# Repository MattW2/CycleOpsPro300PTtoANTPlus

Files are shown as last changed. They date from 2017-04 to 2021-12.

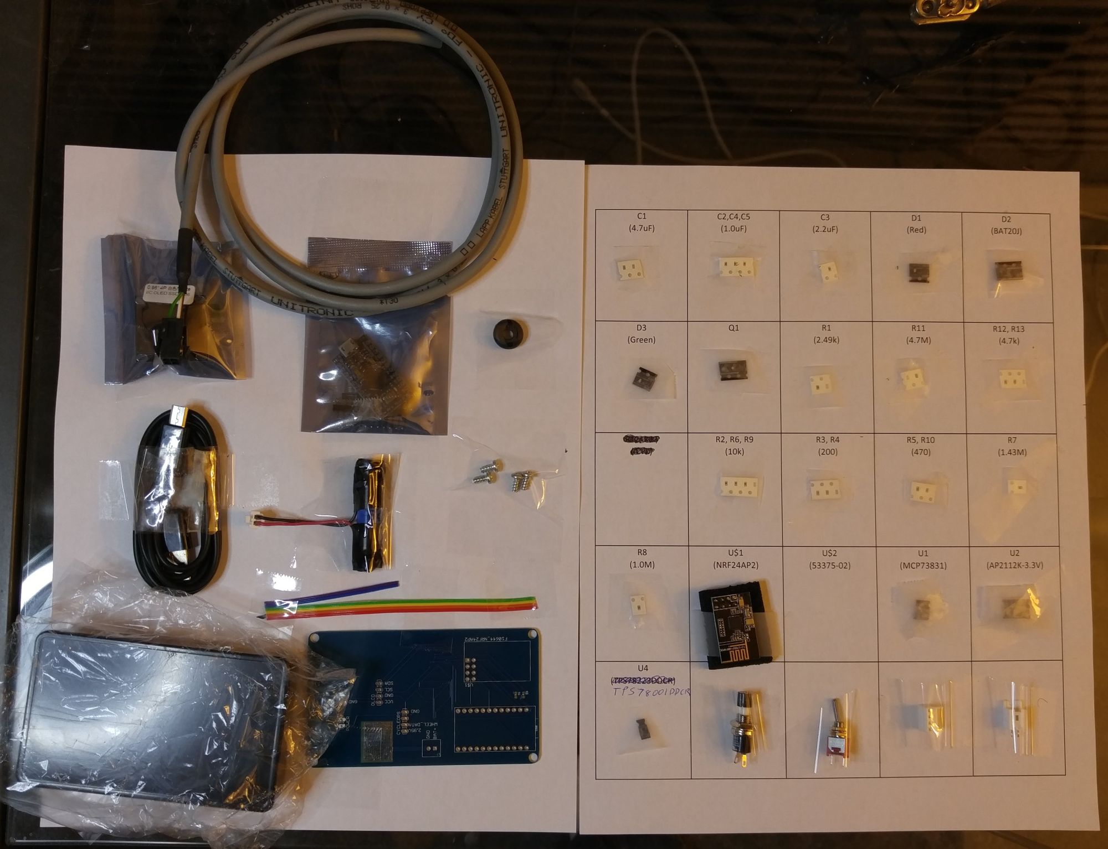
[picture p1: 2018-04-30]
PARTS KIT/Parts Kit.jpg

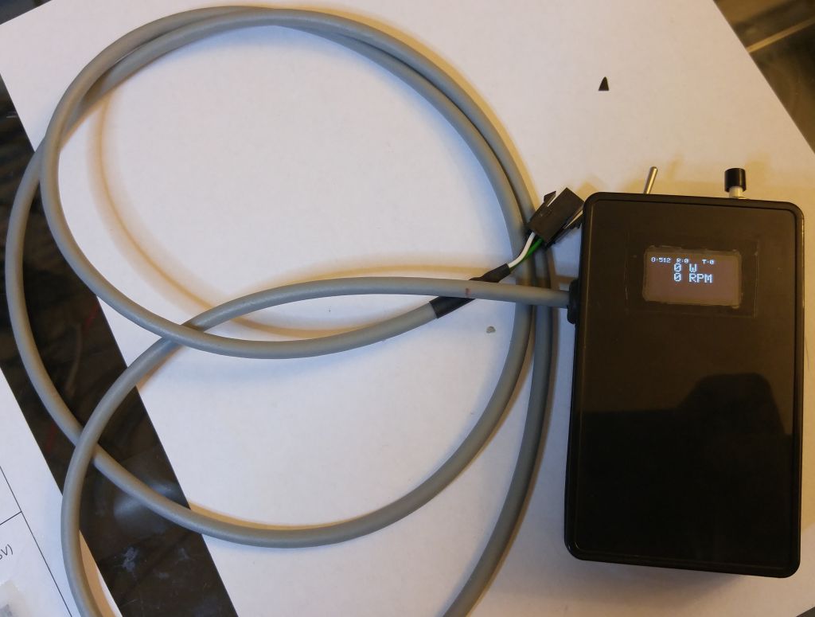
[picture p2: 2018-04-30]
PARTS KIT/Completed Unit.jpg

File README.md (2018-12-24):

# CycleOpsPro300PTtoANTPlus
Read in the raw data from the CycleOps Pro 300PT Indoor Cycle wheel and output it as a ANT+ signal using an Arduino and Nordic nRF24AP

## Background
I got a really good deal on Craigslist on this indoor bike. I had also recently become addicted to Zwift and really wanted to be able to use this with Zwift rather than use my bike on a trainer. The included computer refused to save data past about 10 minutes making it all but worthless for saving training sessions. As I find time I'll be documenting the reverse engineering and build at [https://www.blinkyme.com/](https://www.blinkyme.com/) see website for project details

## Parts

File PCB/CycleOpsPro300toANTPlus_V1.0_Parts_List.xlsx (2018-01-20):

Part | Value | Package | Description | Mouser Part # | Link | Device | Cost
B1 | PRO MICRO | SPARKFUN_PRO_MICRO | SparkFun Pro Micro |  | http://www.ebay.com/itm/Leonardo-Pro-Micro-ATmega32U4-8MHz-3-3V-Replace-ATmega328-Arduino-Pro-Mini-/131694495857 | SPARKFUN_PRO_MICRO | 8.73
Battery 14500 3.7V Li-Ion |  |  |  |  | http://www.dx.com/p/trustfire-protected-14500-3-7v-900mah-lithium-batteries-2-pack-blue-19626 |  | 2.865
C1 | 4.7uF | 0603-CAP | Capacitor | 581-06036D475MAT4A |  | CAP0603-CAP | 0.22
C2, C4, C5 | 1.0uF | 0603-CAP | Capacitor | 581-06036D105MAT2A |  | CAP0603-CAP | 0.11
C3 | 2.2uF | 0603-CAP | Capacitor | 581-06036D225MAT2A |  | CAP0603-CAP | 0.17
D1 | RED | LED-0603 | LEDs | 645-598-8010-107F |  | LED0603 | 0.45
D2 | BAT20J | SOD-323 | Schottky diodes in SFE's production catalog | 511-BAT20JFILM |  | DIODE-SCHOTTKY-BAT20J
D3 | GREEN | LED-0603 | LEDs | 645-598-8070-107F |  | LED0603 | 0.45
Molex Micro-Fit 4 Circuit plug Housing |  |  |  | 538-43020-0400 |  |  | 0.38
Molex Micro-Fit Pins |  |  |  | 538-43031-0007 |  |  | 0.92
OLED Display |  |  |  |  | http://www.ebay.com/itm/191785893008?_trksid=p2057872.m2749.l2649&ssPageName=STRK%3AMEBIDX%3AIT |  | 11.95
Power Switch |  | Mountain Switch | Toggle Switches SPST OFF-ON | 108-0041-EVX |  | 108-0041-EVX | 2.83
Project Case |  |  |  |  | http://www.ebay.com/itm/5-PCS-Plastic-Instrument-Case-Electronic-Project-Box-Enclosure-Instrument-Case-/272321315057 |  | 0.9
Q1 | 2.5A/30V | SOT23-3 | Generic PMOSFET | 621-DMG2307L-7 |  | MOSFET-PCHANNELDMG2307L
R1 | 2.49K | 0603-RES | Resistor | 660-RK73H1JTTD2491F |  | RESISTOR0603-RES
R11 | 4.7M | 0603-RES | Resistor | 660-RK73B1JTTDD475J |  | RESISTOR0603-RES
R12, R13 | 4.7K | 0603-RES | Resistor | 667-ERJ-3GEYJ472V |  | RESISTOR0603-RES
R2, R6, R9 | 10K | 0603-RES | Resistor | 660-RK73H1JTTD1002F |  | RESISTOR0603-RES
R3, R4 | 200 | 0603-RES | Resistor | 660-RK73H1JTTD2000F |  | RESISTOR0603-RES
R5, R10 | 470 | 0603-RES | Resistor | 660-RK73H1JTTD4700F |  | RESISTOR0603-RES
R7 | 1.43M | 0603-RES | Resistor | 71-CRCW06031M43FKEA |  | RESISTOR0603-RES
R8 | 1.0M | 0603-RES | Resistor | 652-CR0603FX-1004ELF |  | RESISTOR0603-RES
Reset Switch |  | Mountain Switch | Pushbutton Switches METAL BODY BLK | 103-1013-EVX |  | 103-1013-EVX | 1.85
U$1 | NRF24AP2 |  | NRF24AP2 Networking Module |  | https://www.aliexpress.com/snapshot/0.html?orderId=82384771664494 | F10644_NRF24AP2 | 15.6
U$2 | 53375-02 | 53375-02 | 2.50MM 2P VERT HDR FRCTN POS LOCK | 538-53375-0210 |  | 53375-02 | 0.43
U1 | MCP73831 | SOT23-5 | Charge management controller | 579-MCP73831T-2ACIOT |  | MCP73831 | 0.6
U2 | AP2112K-3.3V | SOT23-5 | Voltage Regulator LDO | 621-AP2112K-3.3TRG1 |  | V_REG_LDOSMD | 0.47
U4 | TPS78001DDCR | SOT95P280X110-5N | Low-Dropout Linear Regulator | 595-TPS78001DDCR |  | TPS78223DDCR | 1
 |  |  |  |  |  | Total | 49.925

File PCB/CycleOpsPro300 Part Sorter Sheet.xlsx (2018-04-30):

C1 (4.7uF) | C2,C4,C5 (1.0uF) | C3 (2.2uF) | D1 (Red) | D2 (BAT20J)
D3 (Green) | Q1 | R1 (2.49k) | R11 (4.7M) | R12, R13 (4.7k)
 | R2, R6, R9 (10k) | R3, R4 (200) | R5, R10 (470) | R7 (1.43M)
R8 (1.0M) | U$1 (NRF24AP2) | U$2 (53375-02) | U1 (MCP73831) | U2 (AP2112K-3.3V)
U4 (TPS78223DDCR)

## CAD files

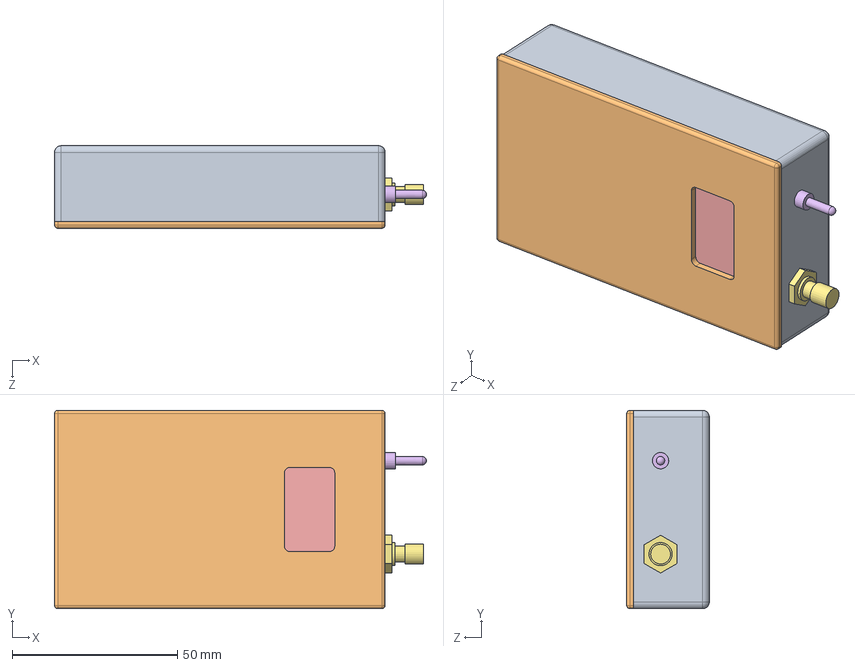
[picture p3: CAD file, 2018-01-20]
CAD/V1/CycleOpsToANTPlus.SLDASM
112.5 x 60.0 x 25.0 mm
Case XDP04-17 Bottom
Case XDP04-17 Top
cycleopspro300toantplus_v10
ARDUINO PRO MICRO
Capacitor 0603 x 5
1X04_1X04 x 2
LED_0603_R
SOD323
LED_0603_G
1X02_1X02 x 2
SOT 23
0603RES_2_5K
Resistor 0603 x 5
0603RES_5 x 5
0603RES_1_0M
0603RES_4_7M
F10644_NRF24AP2_F10644_NRF24AP2
SOT 23-5 x 2
SOT95P280X1105N_TPS78223DDCR
OLED_27x27_r2
Battery 14500

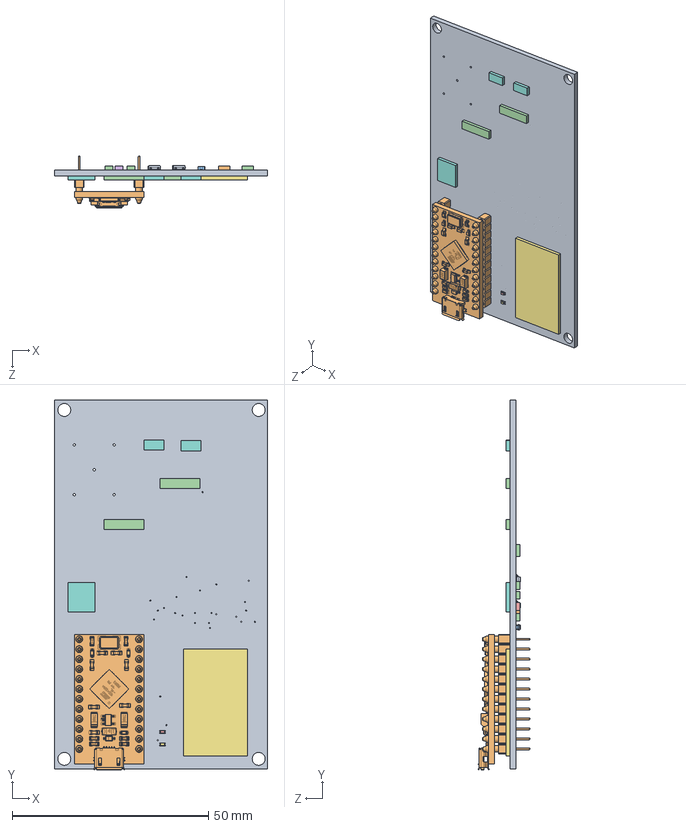
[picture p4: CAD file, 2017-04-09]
CAD/V1/cycleopspro300toantplus_v10.SLDASM
54.4 x 94.3 x 13.3 mm
cycleopspro300toantplus_v10
ARDUINO PRO MICRO
Capacitor 0603 x 5
1X04_1X04 x 2
LED_0603_R
SOD323
LED_0603_G
1X02_1X02 x 2
SOT 23
0603RES_2_5K
Resistor 0603 x 5
0603RES_5 x 5
0603RES_1_0M
0603RES_4_7M
F10644_NRF24AP2_F10644_NRF24AP2
SOT 23-5 x 2
SOT95P280X1105N_TPS78223DDCR

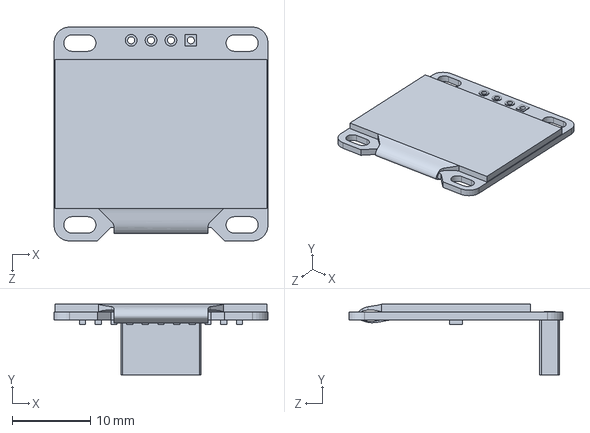
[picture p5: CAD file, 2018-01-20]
CAD/V1/OLED_27x27_r2.SLDPRT
27.3 x 9.00 x 27.3 mm

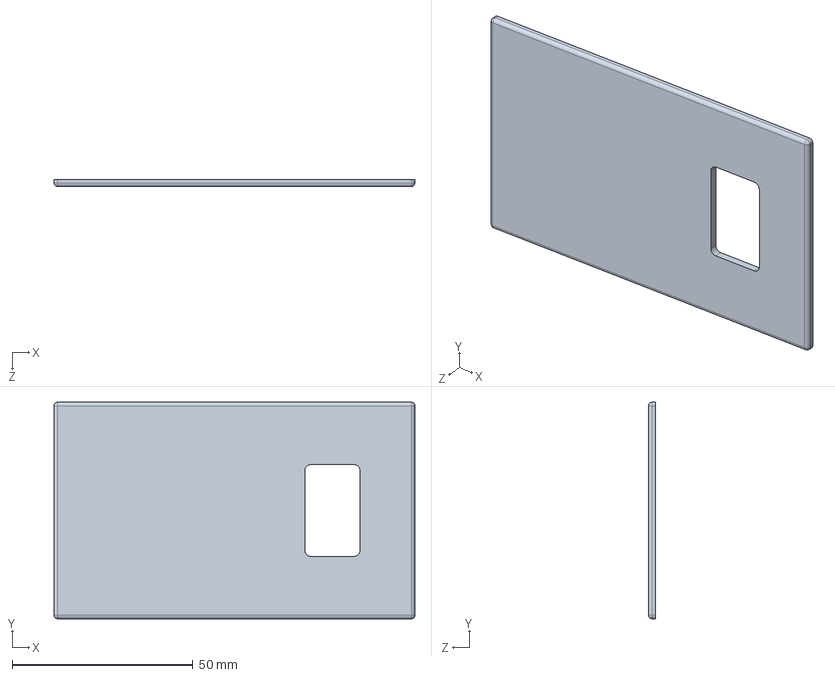
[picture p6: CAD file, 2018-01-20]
CAD/V1/Case XDP04-17 Top.SLDPRT
100.0 x 60.0 x 2.00 mm

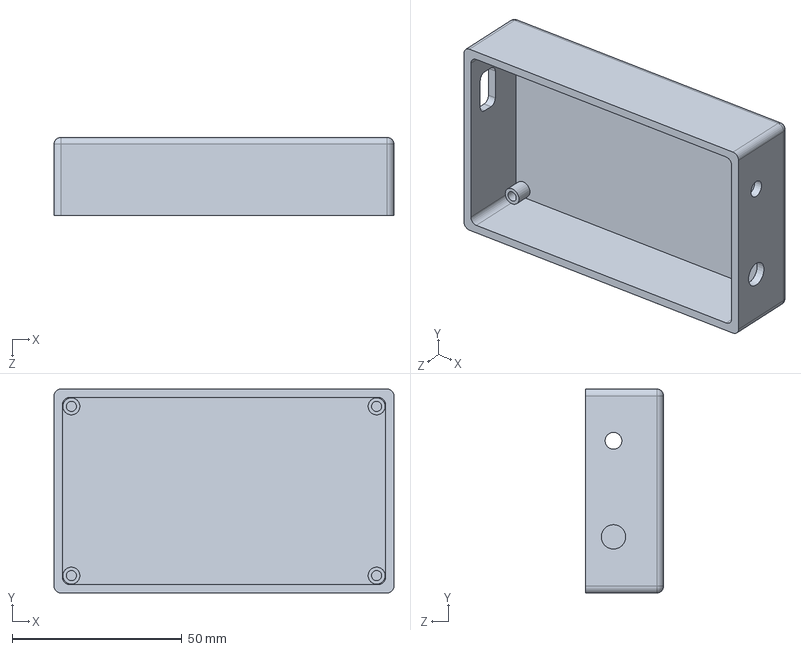
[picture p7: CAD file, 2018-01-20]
CAD/V1/Case XDP04-17 Bottom.SLDPRT
100.0 x 60.0 x 23.0 mm

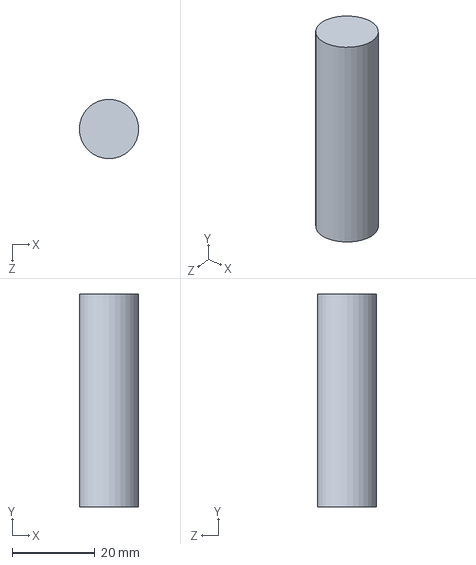
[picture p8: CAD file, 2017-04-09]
CAD/V1/Battery 14500.SLDPRT
14.4 x 51.4 x 14.4 mm

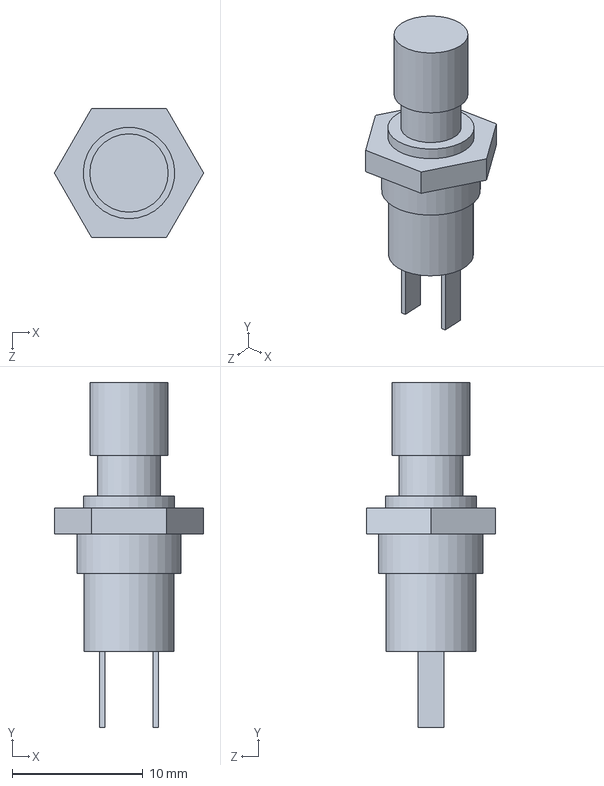
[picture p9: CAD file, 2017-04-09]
CAD/V1/Mountain Switch 103-1013-EVX.SLDPRT
11.4 x 26.4 x 9.90 mm

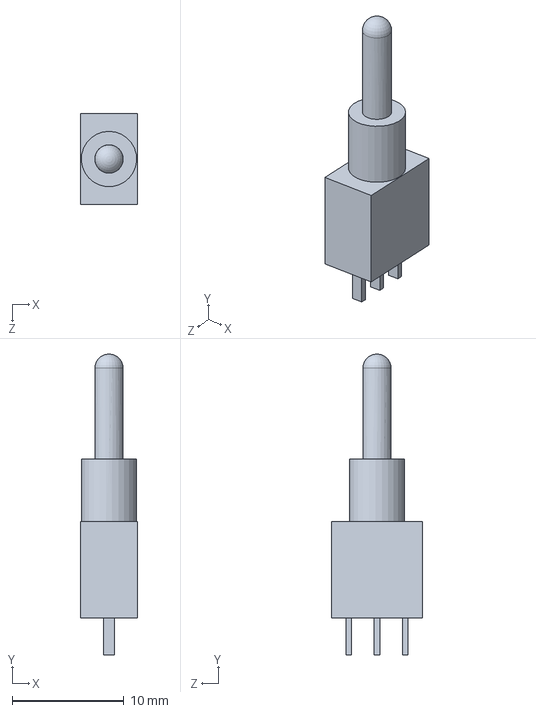
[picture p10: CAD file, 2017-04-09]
CAD/V1/Mountain Switch 108-0041-EVX.SLDPRT
5.08 x 26.9 x 8.13 mm

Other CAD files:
CAD/V1/Case XDP04-17 Bottom 8x11.SLDDRW
CAD/V1/Case XDP04-17 Bottom.SLDDRW

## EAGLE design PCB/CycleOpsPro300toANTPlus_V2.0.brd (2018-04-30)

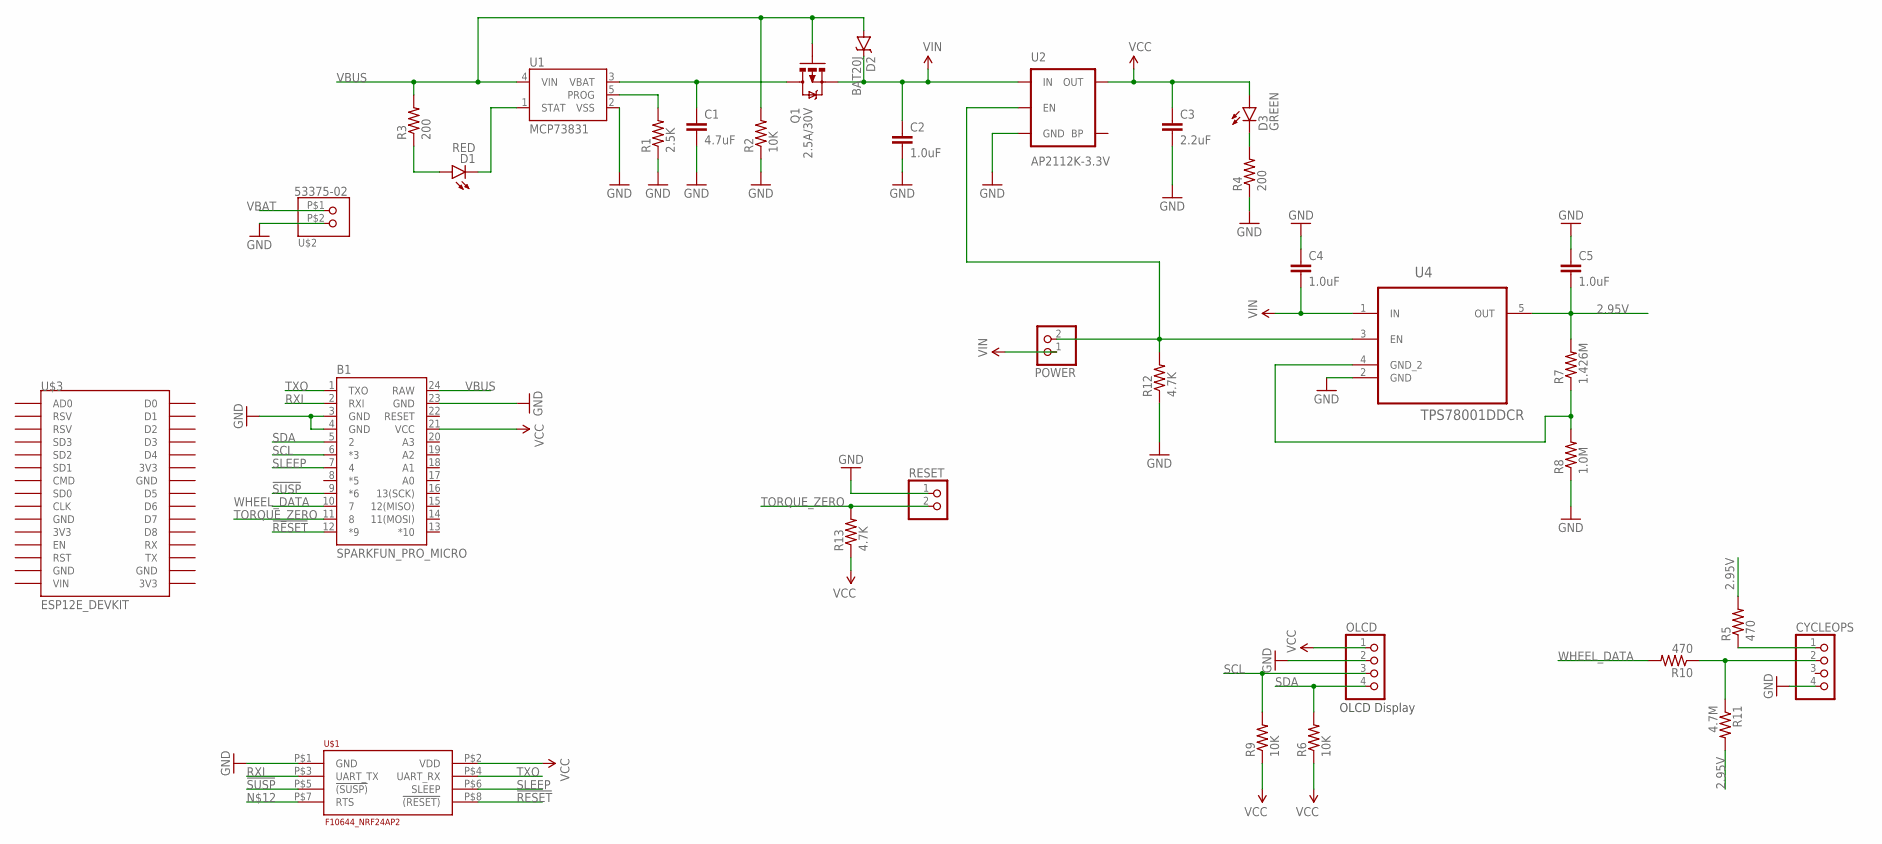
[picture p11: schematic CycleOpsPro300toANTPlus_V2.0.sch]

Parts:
B1: SPARKFUN_PRO_MICRO
C1: 4.7uF; 0603-CAP
C2, C4, C5: 1.0uF; 0603-CAP
C3: 2.2uF; 0603-CAP
CYCLEOPS: PINHD-1X4; 1X04
D1: RED; LED-0603
D2: BAT20J; SOD-323
D3: GREEN; LED-0603
OLCD: PINHD-1X4; 1X04
POWER: PINHD-1X2; 1X02
Q1: 2.5A/30V; SOT23-3
R1: 2.5K; 0603-RES
R2, R6, R9: 10K; 0603-RES
R3, R4: 200; 0603-RES
R5, R10: 470; 0603-RES
R7: 1.426M; 0603-RES
R8: 1.0M; 0603-RES
R11: 4.7M; 0603-RES
R12, R13: 4.7K; 0603-RES
RESET: PINHD-1X2; 1X02
U1: MCP73831; SOT23-5
U2: AP2112K-3.3V; SOT23-5
U4: TPS78001DDCR; SOT95P280X110-5N
U$1: F10644_NRF24AP2
U$2: 53375-02
U$3: ESP12E_DEVKIT

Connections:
2.95V: C5.2, R5.2, R7.2, R11.2, U4.5 (OUT)
!RESET: B1.12 (*9), U$1.P$8 (!(RESET))
!SUSP: B1.9 (*6), U$1.P$5 (!(SUSP))
GND: B1.3 (GND), B1.4 (GND), B1.23 (GND), C1.2, C2.2, C3.2, C4.1, C5.1, CYCLEOPS.4, OLCD.2, R1.1, R2.1, R4.1, R8.1, R12.1, RESET.1, U1.2 (VSS), U2.2 (GND), U4.2 (GND), U$1.P$1 (GND), U$2.P$2
unnamed: D1.A, R3.1
unnamed: D1.C, U1.1 (STAT)
unnamed: CYCLEOPS.1, R5.1
unnamed: R1.2, U1.5 (PROG)
unnamed: CYCLEOPS.2, R10.1, R11.1
unnamed: D3.C, R4.2
unnamed: POWER.2, R12.2, U2.3 (EN), U4.3 (EN)
unnamed: R7.1, R8.2, U4.4 (GND_2)
RXI: B1.2 (RXI), U$1.P$3 (UART_TX)
SCL: B1.6 (*3), OLCD.3, R9.2
SDA: B1.5 (2), OLCD.4, R6.2
SLEEP: B1.7 (4), U$1.P$6 (SLEEP)
TORQUE_ZERO: B1.11 (8), R13.2, RESET.2
TXO: B1.1 (TXO), U$1.P$4 (UART_RX)
VBAT: C1.1, Q1.3 (D), U1.3 (VBAT), U$2.P$1
VBUS: B1.24 (RAW), D2.A, Q1.1 (G), R2.2, R3.2, U1.4 (VIN)
VCC: B1.21 (VCC), C3.1, D3.A, OLCD.1, R6.1, R9.1, R13.1, U2.5 (OUT), U$1.P$2 (VDD)
VIN: C2.1, C4.2, D2.C, POWER.1, Q1.2 (S), U2.1 (IN), U4.1 (IN)
WHEEL_DATA: B1.10 (7), R10.2

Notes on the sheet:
OLCD Display

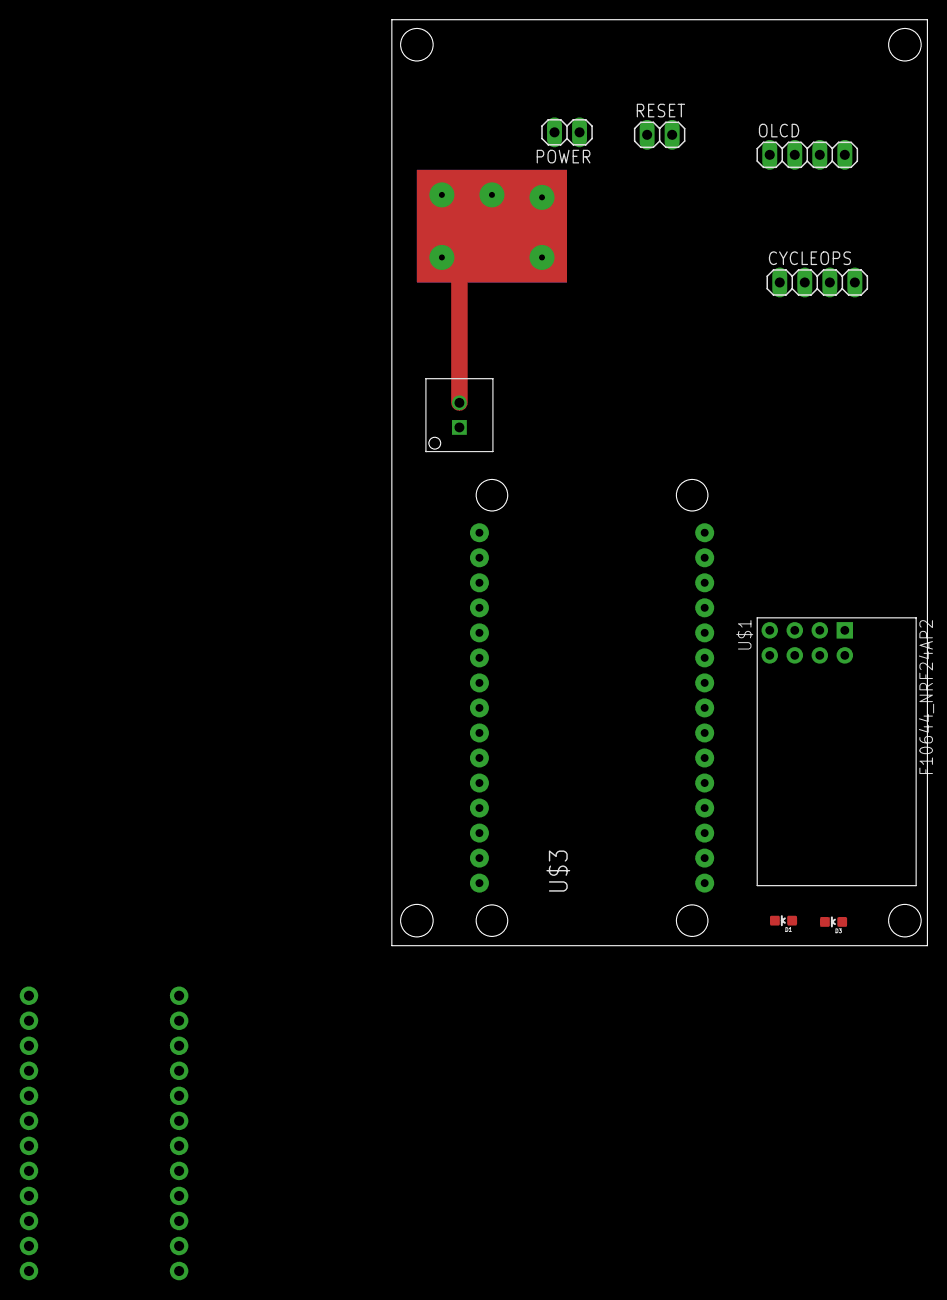
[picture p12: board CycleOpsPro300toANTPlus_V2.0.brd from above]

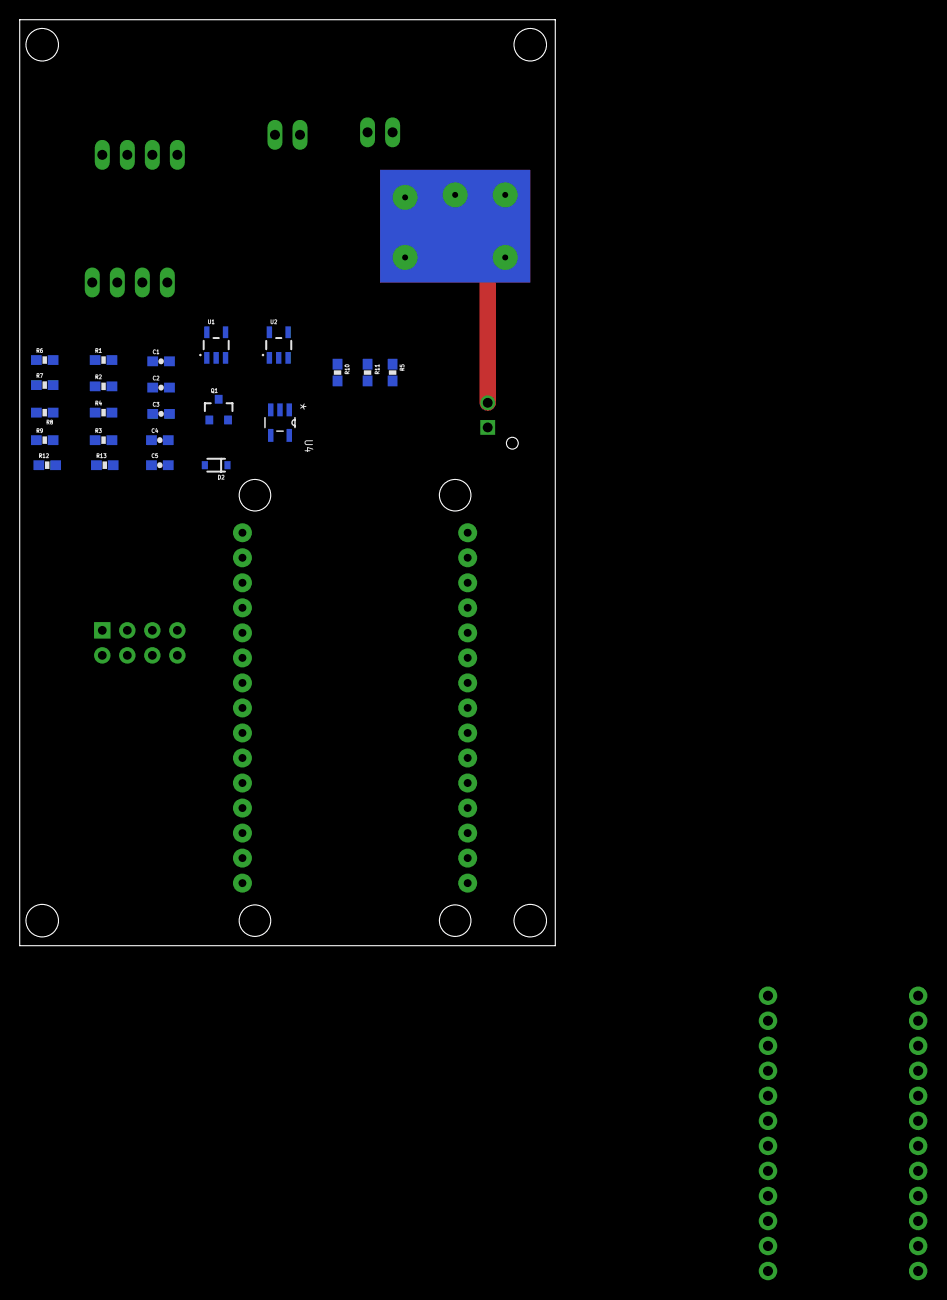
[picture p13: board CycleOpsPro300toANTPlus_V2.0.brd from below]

Board: 2 copper layers, 54.4 x 94.0 mm, 33 parts (23 on the bottom side), 23 nets.

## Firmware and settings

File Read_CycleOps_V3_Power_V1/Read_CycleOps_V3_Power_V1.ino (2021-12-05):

#define UCHAR unsigned char
#define MESG_TX_SYNC ((UCHAR)0xA4)
#define MESG_SYSTEM_RESET_ID ((UCHAR)0x4A)
#define MESG_NETWORK_KEY_ID ((UCHAR)0x46)
#define MESG_ASSIGN_CHANNEL_ID ((UCHAR)0x42)
#define MESG_CHANNEL_ID_ID ((UCHAR)0x51)
#define MESG_CHANNEL_RADIO_FREQ_ID ((UCHAR)0x45)
#define MESG_CHANNEL_MESG_PERIOD_ID ((UCHAR)0x43) // Set channel period 0x43
#define MESG_RADIO_TX_POWER_ID ((UCHAR)0x47) // Set Tx Power 0x47
#define MESG_CHANNEL_SEARCH_TIMEOUT_ID ((UCHAR)0x44) // Set Channel Search Timeout 0x44
#define MESG_OPEN_CHANNEL_ID ((UCHAR)0x4B) // ID Byte 0x4B
#define MESG_BROADCAST_DATA_ID ((UCHAR)0x4E)

//OLED Display
#define USE_OLCD
#include "SSD1306Ascii.h"
#include "SSD1306AsciiAvrI2c.h"

#include <Bounce2.h>

//Pins for ANT+ Device Display
#define RTS_PIN 2
#define SUSPEND 6
#define SLEEP 4
#define RESET 9

//Pins for Torque Zero Button
#define TORQUE_ZERO_PIN 8

//Pins for Data and Debug
#define WHEEL_DATA 7
#define CLOCK_OUT 16
#define ERROR_OUT 10

//Conversion Constants
#define WHEEL_SPEED_CONVERSION 6283185.30718
#define TORQUE_INLBS_TO_NM 0.112984829
// #define WHEEL_CIRCUMFERENCE_MM 1827 //this is not used in code, but needed to set your bike computer to read the correct speed
#define BIKE_WHEEL_ROTATIONS_PER_SEC_PER_RPM 0.06303072228348
#define MPH_PER_RPM 0.257173772

#if defined(USE_OLCD)
//OLED Display
#define OLED_RESET -1
// 0X3C+SA0 - 0x3C or 0x3D
#define I2C_ADDRESS 0x3C
SSD1306AsciiAvrI2c display; 
#endif

#define MAX_DATA_PAGE_INDEX 5


// ****************************************************************************
// *************************  GLOBALS for Read CycelOps************************
// ****************************************************************************
static const double WHEEL_SLOPE = 527.2213800;
static const double WHEEL_OFFSET = -3181.8199961;
static const double GEAR_RATIO = 0.269230769;
static const bool VALID_START_DATA[15] = {0,1,1,1,1,0,1,0,1,1,0,1,1,0,1};

int TORQUE_OFFSET = 512;

boolean start_reading;
boolean reset_ready;
volatile boolean new_data_set;
volatile boolean is_data_bit;
volatile int bit_read_count;
int bit_delay;

int data_bits = 50;

//Timers
unsigned long current_time_us;
volatile unsigned long last_time_us;
unsigned long delay_reset_us;
unsigned long wheel_time_now_ms;
unsigned long wheel_time_last_ms;

//Timers and switch for finding error bits
volatile unsigned long last_rising_edge;
volatile unsigned long last_falling_edge;
volatile boolean error_bit_found;
boolean data_being_read;

//array to store data
boolean data_input[70];
int data_position;
int torque;
int torque_in_lbs;
unsigned int wheel_speed;
unsigned int CycleOps_CheckSum;
double wheel_period; //time in us for 1 wheel rotation

// Instantiate a Bounce object for zeroing the torque
Bounce torque_zero_input = Bounce();


// ****************************************************************************
// *************************  GLOBALS for Power Out**********************
// ****************************************************************************

const int Mag_pickup = 3; // the number of the pushbutton pin
//int pin = 13;
volatile int state = LOW;
//unsigned long time1;
//unsigned long time2;
//unsigned long period;

double omega;
double torque_kgm;
double torque_Nm;

byte ANT_event = 0;
uint16_t ANT_INST_power = 0;
uint16_t ANT_power = 0;
uint8_t ANT_icad = 0; // Corrected Cadence
double powerconst;

// ****************************************************************************
// *************************  GLOBALS for Cadance Out**************************
// ****************************************************************************
uint8_t ANT_wheel_ticks = 0;
uint16_t ANT_wheel_period = 0;
uint16_t ANT_accumulated_torque = 0;
double Bike_Speed_MPH = 0;

boolean recalc = 0;

long lastDebounceTime = 0; // the last time the output pin was toggled
long debounceDelay = 30; // the debounce time; increase if the output flickers
int buttonState; // the current reading from the input pin
int lastButtonState = LOW; // the previous reading from the input pin
boolean sent = 0;
int data_page_index = 0;

void setup()
{
	//setup for CycelOp
	data_position = 0;
	start_reading = 0;
	new_data_set = 0;
	reset_ready = 0;
	//wheel_time_now = 0;
	//wheel_time_last = 0;
	bit_read_count = 0;

	torque = 0;
	torque_in_lbs = 0;
	ANT_icad = 0;
	ANT_INST_power = 0;
	CycleOps_CheckSum = 0;

  ANT_wheel_ticks = 0;
  ANT_wheel_period = 0;
  ANT_accumulated_torque = 0;
	
	last_rising_edge = 0;
	last_falling_edge = 0;
	error_bit_found = 0;
	data_being_read = 0;

  data_page_index = 0;

	digitalWrite(CLOCK_OUT, LOW);
	digitalWrite(ERROR_OUT, LOW);

	pinMode(WHEEL_DATA, INPUT);
	pinMode(CLOCK_OUT, OUTPUT);
	pinMode(ERROR_OUT, OUTPUT);

	//setup for Torque zero button
	pinMode(TORQUE_ZERO_PIN, INPUT_PULLUP);
	// After setting up the button, setup the Bounce instance :
	torque_zero_input.attach(TORQUE_ZERO_PIN);
	torque_zero_input.interval(50); // interval in ms

	//Setup for PowerOut
	pinMode(SUSPEND, OUTPUT);           // set pin to output
	pinMode(SLEEP, OUTPUT);             // set pin to output
	pinMode(RESET, OUTPUT);             // set pin to output
	pinMode(RTS_PIN, INPUT);            // set pin to input

	digitalWrite(RESET, HIGH);        // turn on pullup resistors
	digitalWrite(SUSPEND, HIGH);      // turn on pullup resistors
	digitalWrite(SLEEP, LOW);         // turn on pullup resistors

	Serial.begin(115200); //this is the USB port serial
	Serial1.begin(9600); //this is the hardware UART

	delay(1000);
	Serial1.flush();

	//reset the ANT+ module
	digitalWrite(RESET, LOW);       // turn on pullup resistors
	delay(5);
	digitalWrite(RESET, HIGH);       // turn on pullup resistors

#if defined(USE_OLCD)
	//Setup for OLCD
	// by default, we'll generate the high voltage from the 3.3v line internally! (neat!)
#if OLED_RESET >= 0
	display.begin(&Adafruit128x64, I2C_ADDRESS, RST_PIN);
#else // OLED_RESET >= 0
	display.begin(&Adafruit128x64, I2C_ADDRESS);
#endif // OLED_RESET >= 0
	// Call display.setI2cClock(frequency) to change from the default frequency.
	display.setFont(Adafruit5x7);    
	display.clear(); 

	// setup display with no data
	display.set1X();
	display.setCursor(0, 0); // begin text at this location, X,Y
	display.print(F("O:"));
	display.setCursor(40, 0); // begin text at this location, X,Y
	display.print(F("R:"));
	display.setCursor(80, 0); // begin text at this location, X,Y
	display.print(F("T:"));
	display.setCursor(0, 1); // begin text at this location, X,Y
	display.set2X();  
	display.print(F("  W:"));  
	display.setCursor(0, 4); // begin text at this location, X,Y  
	display.print(F("RPM:"));
#endif

	delay(50);
	initiate();
	delay(20);

	ant_send_basicpower();

	//interrupt for wheel data from CycleOps
	attachInterrupt(digitalPinToInterrupt(WHEEL_DATA), find_start_of_wheel_data, CHANGE);

	current_time_us = micros();
	last_time_us = current_time_us;
  
  wheel_time_now_ms = millis();
  wheel_time_last_ms = wheel_time_now_ms;
}

void loop()
{
	int i;
  unsigned long wheel_time_delta_ms;
  
	current_time_us = micros();

	if (new_data_set) {
		start_reading = 1;
		//Serial.print("found start = ");
		//Serial.println(current_time_us);
		new_data_set = 0;
	}

	if (is_data_bit)
		//bit_delay = 1765;
		bit_delay = 1875; //delay for data bits
	else
		//bit_delay = 1525;
		bit_delay = 8780; //delay for dead bits

	if (is_data_bit && bit_read_count == 4) {
		is_data_bit = 0;
		bit_read_count = 0;
	}

	if (!is_data_bit && bit_read_count == 1) {
		is_data_bit = 1;
		bit_read_count = 0;
	}

	if ((current_time_us - last_time_us) >= bit_delay) {
		if (start_reading && data_position < data_bits) {
			last_time_us = current_time_us;
			read_wheel_data();
			bit_read_count++;
		}
	}
	
	if (data_position == data_bits) { //time to spit out the data and reset
		start_reading = 0;
		//test if data is valid
		if (memcmp(data_input,VALID_START_DATA,15) == 0 && !error_bit_found) {			
			read_torque();
			read_speed();
			//read_checkSum();
			recalc = 1;
			data_position = 0;
			delay_reset_us = current_time_us;
			reset_ready = 1;
			error_bit_found = 0;
			digitalWrite(ERROR_OUT, LOW);
		} else { //data is not valid, clear buffer
			if (error_bit_found) {
				Serial.println(F("ERROR BIT FOUND"));
			}
			data_position = 0;
			delay_reset_us = current_time_us;
			reset_ready = 1;
			error_bit_found = 0;
			digitalWrite(ERROR_OUT, LOW);
		}
	}
	
	if (reset_ready && ((current_time_us - delay_reset_us) > 100000)) {
		reset_ready = 0;
		bit_read_count = 0;
		error_bit_found = 0;
	}

	if (recalc == 1)
	{
		ANT_icad = uint8_t(omega * 9.549296586 * GEAR_RATIO); // Cadence (RPM)

		ANT_INST_power = uint16_t(torque_Nm * omega); // Instant power calculation
		ANT_power += ANT_INST_power; // Incremental power calculation

    //values for wheel speed Data Page (0x11)
    wheel_time_now_ms = millis();
    wheel_time_delta_ms = wheel_time_now_ms - wheel_time_last_ms;
    wheel_time_last_ms = wheel_time_now_ms;
    
    ANT_wheel_ticks += uint8_t((wheel_time_delta_ms * ANT_icad * BIKE_WHEEL_ROTATIONS_PER_SEC_PER_RPM) / 1000);
    if (ANT_icad > 0)
    {
      ANT_wheel_period += uint16_t(1/(ANT_icad * BIKE_WHEEL_ROTATIONS_PER_SEC_PER_RPM ) * 2048);
    }
    ANT_accumulated_torque += uint16_t(torque_Nm * 32); // Accumulated torque calculation
    Bike_Speed_MPH = ANT_icad * MPH_PER_RPM;
    
	//write data to serial out
		for (i = 0; i <= data_bits; i++) {
			Serial.print(data_input[i]);
		}
		Serial.print(F(" "));
		Serial.print(torque, DEC);
		Serial.print(F(" "));
		Serial.print(wheel_speed, DEC);
		Serial.print(F(" "));
		Serial.print(ANT_icad, 1);
		Serial.print(F(" "));
		Serial.print(ANT_INST_power, 1);
		Serial.print(F(" "));
		//Serial.print(CycleOps_CheckSum, DEC);
    Serial.print(ANT_wheel_ticks, 1);
    Serial.print(F(" "));
    Serial.print(ANT_wheel_period, 1);
    Serial.print(F(" "));
    Serial.print(ANT_accumulated_torque, 1);
		Serial.println(F(""));

    if (data_page_index == 0)
    {
      ANT_event++;
      ant_send_basicpower(); // Main ANT tranmission of Basic Power Data and RPM
    }
    if (data_page_index >= 1)
    {
      ANT_event++;
      ant_send_wheel_torque(); //Main Ant transmission of wheel speed (for bike speed)
    }
    data_page_index++;
    if (data_page_index >= MAX_DATA_PAGE_INDEX)
    {
      data_page_index = 0;
    }
		Serial1.flush();

#if defined(USE_OLCD)
		update_OLED();
#endif
		recalc = 0;
	}

	// Update the Bounce instance :
	torque_zero_input.update();
	if (!torque_zero_input.read())
	{
		TORQUE_OFFSET = torque;
		update_OLED();
	}

}

UCHAR checkSum(UCHAR *data, int length)
{
	int i;
	UCHAR chksum = data[0];
	for (i = 1; i < length; i++)
	chksum ^= data[i]; // +1 since skip prefix sync code, we already counted it
	return chksum;
}

void reset ()
{
	uint8_t buf[5];
	buf[0] = MESG_TX_SYNC; // SYNC Byte 0xA4
	buf[1] = 0x01; // LENGTH Byte
	buf[2] = MESG_SYSTEM_RESET_ID; // 0x4A
	buf[3] = 0x00; // Data Byte N (N=LENGTH)
	buf[4] = checkSum(buf, 4);
	ANTsend(buf, 5);
}

void SetNetwork() //thisisANT.com and become an ANT+ Adopter
{
	uint8_t buf[13];
	buf[0] = MESG_TX_SYNC; // SYNC Byte 0xA4
	buf[1] = 0x09; // LENGTH Byte
	buf[2] = MESG_NETWORK_KEY_ID; // ID Byte 0x46
	buf[3] = 0x00; // Data Byte N (Network Number)
	buf[4] = 0xB9; // Data Byte N (Public Network Key)
	buf[5] = 0xA5; // Data Byte N (Public Network Key)
	buf[6] = 0x21; // Data Byte N (Public Network Key)
	buf[7] = 0xFB; // Data Byte N (Public Network Key)
	buf[8] = 0xBD; // Data Byte N (Public Network Key)
	buf[9] = 0x72; // Data Byte N (Public Network Key)
	buf[10] = 0xC3; // Data Byte N (Public Network Key)
	buf[11] = 0x45; // Data Byte N (Public Network Key)
	buf[12] = checkSum(buf, 12);
	ANTsend(buf, 13);
}
void assignch()
{
	uint8_t buf[7];
	buf[0] = MESG_TX_SYNC; // SYNC Byte 0xA4
	buf[1] = 0x03; // LENGTH Byte
	buf[2] = MESG_ASSIGN_CHANNEL_ID; // 0x42
	buf[3] = 0x00; // Channel Number
	buf[4] = 0x10; // Channel Type
	buf[5] = 0x00; // Network Number
	buf[6] = checkSum(buf, 6);
	ANTsend(buf, 7);
}

void SetChID()
{
	uint8_t buf[9];
	buf[0] = MESG_TX_SYNC; // SYNC Byte 0xA4
	buf[1] = 0x05; // LENGTH Byte
	buf[2] = MESG_CHANNEL_ID_ID; // Assign Channel ID 0x51
	buf[3] = 0x00; // channel number
	buf[4] = 0x06; // Device number
	buf[5] = 0x00; // Device number
	buf[6] = 0x0B; //Device type ID
	buf[7] = 0x00; //Transmission type -CHANGED
	buf[8] = checkSum(buf, 8);
	ANTsend(buf, 9);
}

void ANTsend(uint8_t buf[], int length) {
	//Serial.print("ANTsend TX: ");
	for (int i = 0 ; i <= length ; i++)
	{
		//Serial.print(buf[i], HEX);
		//Serial.print(" ");
		Serial1.write(buf[i]);
	}
	//Serial.println("");
}
void SetFreq()
{
	uint8_t buf[6];
	buf[0] = MESG_TX_SYNC; // SYNC Byte 0xA4
	buf[1] = 0x02; // LENGTH Byte
	buf[2] = MESG_CHANNEL_RADIO_FREQ_ID; // Set Channel RF Freq 0x45
	buf[3] = 0x00; // Channel number
	buf[4] = 0x39; // Frequency
	buf[5] = checkSum(buf, 5);
	ANTsend(buf, 6);
}

void SetPeriod()
{
	uint8_t buf[7];
	buf[0] = MESG_TX_SYNC; // SYNC Byte 0xA4
	buf[1] = 0x03; // LENGTH Byte
	buf[2] = MESG_CHANNEL_MESG_PERIOD_ID; // Set channel period 0x43
	buf[3] = 0x00; // Channel number
	buf[4] = 0xF6; // Messaging Period byte1
	buf[5] = 0x1f; // Messaging period byte2
	buf[6] = checkSum(buf, 6);
	ANTsend(buf, 7);
}

void SetPower()
{
	uint8_t buf[6];
	buf[0] = MESG_TX_SYNC; // SYNC Byte 0xA4
	buf[1] = 0x02; // LENGTH Byte
	buf[2] = MESG_RADIO_TX_POWER_ID; // Set Tx Power 0x47
	buf[3] = 0x00; // Channel Number
	buf[4] = 0x03; // Tx power
	buf[5] = checkSum(buf, 5);
	ANTsend(buf, 6);
}

void SetTimeout()
{
	uint8_t buf[6];
	buf[0] = MESG_TX_SYNC; // SYNC Byte 0xA4
	buf[1] = 0x02; // LENGTH Byte
	buf[2] = MESG_CHANNEL_SEARCH_TIMEOUT_ID; // Set Channel Search Timeout 0x44
	buf[3] = 0x00; // Channel number
	buf[4] = 0x1E; // Set timeout
	buf[5] = checkSum(buf, 5);
	ANTsend(buf, 6);
}

void OpenChannel()
{
	uint8_t buf[5];
	buf[0] = MESG_TX_SYNC; // SYNC Byte 0xA4
	buf[1] = 0x01; // LENGTH Byte
	buf[2] = MESG_OPEN_CHANNEL_ID; // ID Byte 0x4B
	buf[3] = 0x00;
	buf[4] = checkSum(buf, 4);
	ANTsend(buf, 5);
}

void initiate()
{
	SetNetwork();
	delay(100);
	assignch();
	delay(100);
	SetChID();
	delay(100);
	SetFreq();
	delay(100);
	SetPeriod();
	delay(100);
	SetPower();
	delay(100);
	SetTimeout();
	delay(100);
	OpenChannel();
	delay(100);
}

void ant_send_basicpower()
{
	uint8_t buf[13];
	buf[0] = MESG_TX_SYNC; // SYNC Byte 0xA4
	buf[1] = 0x09; // LENGTH Byte
	buf[2] = MESG_BROADCAST_DATA_ID; // 0x4E
	buf[3] = 0x00; // Channel number
	buf[4] = 0x10; // Standard Power-Only Message, Byte 0
	buf[5] = ANT_event; // Power Event Count, Byte 1
	buf[6] = 0xFF; // Pedal Power, Byte 2, 0xFF, Pedal Power Not Used
	buf[7] = ANT_icad; // Instant Cadence, RPM, Byte 3
	buf[8] = byte(ANT_power & 0xFF); // Accumulated power LSB, Byte 4
	buf[9] = byte((ANT_power >> 8) & 0xFF); // Accumulated power MSB, Byte 5
	buf[10] = byte(ANT_INST_power & 0xFF); // Instant power LSB, Byte 6
	buf[11] = byte((ANT_INST_power >> 8) & 0xFF); // Instant power MSB, Byte 7
	buf[12] = checkSum(buf, 12);
	ANTsend(buf, 13);
}

void ant_send_wheel_torque()
{
  uint8_t buf[13];
  buf[0] = MESG_TX_SYNC; // SYNC Byte 0xA4
  buf[1] = 0x09; // LENGTH Byte
  buf[2] = MESG_BROADCAST_DATA_ID; // 0x4E
  buf[3] = 0x00; // Channel number
  buf[4] = 0x11; // 0x11 – sensor measures torque at wheel, Byte 0
  buf[5] = ANT_event; // Event counter increments with each information update, Byte 1
  buf[6] = byte(ANT_wheel_ticks); // Wheel tick count increments with each wheel revolution, Byte 2
  buf[7] = ANT_icad; // Instant Cadence, RPM, Byte 3
  buf[8] = byte(ANT_wheel_period & 0xFF); // Accumulated wheel period LSB, Byte 4
  buf[9] = byte((ANT_wheel_period >> 8) & 0xFF); // Accumulated wheel period  MSB, Byte 5
  buf[10] = byte(ANT_accumulated_torque & 0xFF); // Accumulated torque LSB, Byte 6
  buf[11] = byte((ANT_accumulated_torque >> 8) & 0xFF); // Accumulated torque MSB, Byte 7
  buf[12] = checkSum(buf, 12);
  ANTsend(buf, 13);
}

//functions for getting data from cycleops
void read_wheel_data() {
	if (start_reading) {
		data_being_read = 1;
		data_input[data_position] = digitalRead(WHEEL_DATA);
		if (!data_input[data_position]) {
			data_being_read = 0;
		}
		digitalWrite(CLOCK_OUT, HIGH);
		if (is_data_bit) {
			delayMicroseconds(200);
		} else {
			delayMicroseconds(100);
		}
		digitalWrite(CLOCK_OUT, LOW);
		data_position++;
	}
}

void find_start_of_wheel_data() {
	//looking for the start of a data packet
	if (data_position ==  0 && reset_ready == 0) {
		//check if it is an error bit
		//wait for the signal to be high for > 7200us
		if(digitalRead(WHEEL_DATA)) {
			do_rising_start_packet();
		} else {
			do_falling_start_packet();			     
		}
	} else if(start_reading == 1) { //we are in the process of reading in a data packet
		if(digitalRead(WHEEL_DATA)) { //we just found a rising edge
			do_rising_mid_packet();
		} else { 						//must be a falling edge
			do_falling_mid_packet();
		}	
	}
	//Serial.print("found start = ");
	//Serial.println(current_time_us);
}

void do_rising_start_packet() {
	last_rising_edge = micros();	
}

void do_falling_start_packet() {
	last_falling_edge = micros();
	if ((last_falling_edge - last_rising_edge) > 7200) {
		new_data_set = 1;
		last_time_us = current_time_us - 700; //without error check use 1050
		is_data_bit = 0;
		bit_read_count = 0;
	}
	data_being_read = 0;
}

void do_rising_mid_packet() {
	last_rising_edge = micros();
}

void do_falling_mid_packet() {
	last_falling_edge = micros();
	if (((last_falling_edge - last_rising_edge) < 1000) && is_data_bit && data_being_read) {
		error_bit_found = 1;
		digitalWrite(ERROR_OUT, HIGH);
	}		
	data_being_read = 0;
}

void read_torque() {
	torque = 0;
	bitWrite(torque, 11, data_input[16]);
	bitWrite(torque, 10, data_input[17]);
	bitWrite(torque, 9, data_input[18]);
	bitWrite(torque, 8, data_input[19]);
	bitWrite(torque, 7, data_input[21]);
	bitWrite(torque, 6, data_input[22]);
	bitWrite(torque, 5, data_input[23]);
	bitWrite(torque, 4, data_input[24]);
	bitWrite(torque, 3, data_input[26]);
	bitWrite(torque, 2, data_input[27]);
	bitWrite(torque, 1, data_input[28]);
	bitWrite(torque, 0, data_input[29]);
	
	torque_in_lbs = (double)torque - (double)TORQUE_OFFSET;
	if (torque_in_lbs < 0) {
		torque_Nm = 0;
		torque_in_lbs = 0;
	} else {
		torque_Nm = (torque_in_lbs) * TORQUE_INLBS_TO_NM;
	}
}

void read_speed() {
	wheel_speed = 0;
	bitWrite(wheel_speed, 11, data_input[31]);
	bitWrite(wheel_speed, 10, data_input[32]);
	bitWrite(wheel_speed, 9, data_input[33]);
	bitWrite(wheel_speed, 8, data_input[34]);
	bitWrite(wheel_speed, 7, data_input[36]);
	bitWrite(wheel_speed, 6, data_input[37]);
	bitWrite(wheel_speed, 5, data_input[38]);
	bitWrite(wheel_speed, 4, data_input[39]);
	bitWrite(wheel_speed, 3, data_input[41]);
	bitWrite(wheel_speed, 2, data_input[42]);
	bitWrite(wheel_speed, 1, data_input[43]);
	bitWrite(wheel_speed, 0, data_input[44]);

	if (wheel_speed == 4095) {
		omega = 0;
	} else {
		wheel_period = wheel_speed * WHEEL_SLOPE + WHEEL_OFFSET;
		omega = WHEEL_SPEED_CONVERSION / wheel_period;
	}
}

void read_checkSum() {
	CycleOps_CheckSum = 0;
	
	bitWrite(CycleOps_CheckSum, 15, data_input[46]);
	bitWrite(CycleOps_CheckSum, 14, data_input[47]);
	bitWrite(CycleOps_CheckSum, 13, data_input[48]);
	bitWrite(CycleOps_CheckSum, 12, data_input[49]);
	bitWrite(CycleOps_CheckSum, 11, data_input[51]);
	bitWrite(CycleOps_CheckSum, 10, data_input[52]);
	bitWrite(CycleOps_CheckSum, 9, data_input[53]);
	bitWrite(CycleOps_CheckSum, 8, data_input[54]);
	bitWrite(CycleOps_CheckSum, 7, data_input[56]);
	bitWrite(CycleOps_CheckSum, 6, data_input[57]);
	bitWrite(CycleOps_CheckSum, 5, data_input[58]);
	bitWrite(CycleOps_CheckSum, 4, data_input[59]);	
	bitWrite(CycleOps_CheckSum, 3, data_input[61]);
	bitWrite(CycleOps_CheckSum, 2, data_input[62]);
	bitWrite(CycleOps_CheckSum, 1, data_input[63]);
	bitWrite(CycleOps_CheckSum, 0, data_input[64]);
}

#if defined(USE_OLCD)
void update_OLED() {
	//char temp_string[4];
	// text display tests
	display.set1X();
	display.setCursor(0, 0); // begin text at this location, X,Y
	display.print(F("O:"));
	display.clearToEOL();
	display.print(TORQUE_OFFSET, 1);
	display.setCursor(40, 0); // begin text at this location, X,Y
	display.print(F("R:"));
	display.print(torque, 1);
	display.setCursor(80, 0); // begin text at this location, X,Y
	display.print(F("T:"));
	display.println(torque_in_lbs, 1);
	display.setCursor(0, 1); // begin text at this location, X,Y
	display.set2X();  
	display.print(F("  W:")); 
	display.clearToEOL();  
	display.println(ANT_INST_power, 1);
	display.setCursor(0, 4); // begin text at this location, X,Y  
	display.print(F("RPM:"));
	display.clearToEOL();
	display.print(ANT_icad, 1);
  display.set1X();
  display.setCursor(0, 6); // begin text at this location, X,Y
  display.print(F("S:"));
  display.clearToEOL();
  display.print(Bike_Speed_MPH, 1);
}
#endif

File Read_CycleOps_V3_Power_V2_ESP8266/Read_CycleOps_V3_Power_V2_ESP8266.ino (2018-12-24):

/* Interface between CycleOps Wired Indoor Trainer and ANT+
Project details avaliable at https://www.blinkyme.com


Thank you to
Brody Kenrick for https://github.com/brodykenrick/ANTPlus_Arduino

Interfacing of Garmin ANT+ device (via a cheap Nordic nRF24AP UART module) to an Arduino.

Hardware
-WEMOS D1 mini, https://wiki.wemos.cc/products:d1:d1_mini
-nRF24AP2 module : https://www.aliexpress.com/item/Free-shipping-NRF24AP2-Networking-Module-8-channel-Serial-Interface-ANT-Networking/32460612988.html

The connector on nRF24AP2 board is (looking from the front, pin 1 is marked []):
[]GND(=VSS) | VDD(=3.3 volts)
UART_TX   | UART_RX
!(SUSP)   | SLEEP
RTS       | !(RESET)

Wiring to the WEMOS D1 mini can be found in the PCB documention.
*/

#include <Arduino.h>

//#define NDEBUG
//#define ANTPLUS_DEBUG //output the ANTPLUS Packets
//#define ANTPLUS_MSG_STR_DECODE // decode ANTPLUS Packets

#define __ASSERT_USE_STDERR
#include <assert.h>

#define ANTPLUS_ON_HW_UART //using a Arduino Pro Micro with "Real" USB serial. This is on Serial, nRF24AP2 will be on Serial

#if !defined(ANTPLUS_ON_HW_UART)
#include <SoftwareSerial.h>
#endif

#include <ANTPlus.h>

#define USE_SERIAL_CONSOLE //!<Use the hardware serial as the console. This needs to be off if using hardware serial for driving the ANT+ module.

#if defined(NDEBUG)
#undef USE_SERIAL_CONSOLE
#endif

//Telnet debuging
#define USE_TELNET_CONSOLE
#define ESP8266

#ifdef USE_TELNET_CONSOLE
#if defined (ESP8266)
#define USE_MDNS true // Use the MDNS ?

// Includes do ESP8266

#include <ESP8266WiFi.h>

#ifdef USE_MDNS
#include <DNSServer.h>
#include <ESP8266mDNS.h>
#endif

#elif defined(ESP32)
//#define USE_MDNS true // Use the MDNS ? //TODO: not tested in Esp32 yet
// Includes do ESP32
#include <WiFi.h>
#ifdef USE_MDNS
#include "ESPmDNS.h"
#endif
#else
#error The board must be ESP8266 or ESP32
#endif // ESP
// Remote debug over telnet - not recommended for production, only for development
#include "RemoteDebug.h"        //https://github.com/JoaoLopesF/RemoteDebug
RemoteDebug Debug;
// SSID and password
const char* ssid = "CatBox";
const char* password = "wass9084586288";

// Host mDNS
#define HOST_NAME "esp_ant"

// Time
uint32_t mLastTime = 0;
uint32_t mTimeSeconds = 0;

// Buildin Led ON ?
boolean mLedON = false;
#endif


//Logging macros
//********************************************************************
#define SERIAL_DEBUG
#define DEBUG_LEVEL 4 //use 4 for all, 0 for basic

#if !defined(USE_SERIAL_CONSOLE)
//Disable logging under these circumstances
#undef SERIAL_DEBUG
#endif

//F() stores static strings that come into existence here in flash (makes things a bit more stable)
#ifdef SERIAL_DEBUG
#if DEBUG_LEVEL == 4
#define SERIAL_DEBUG_PRINT(x)         (Serial1.print(x))
#define SERIAL_DEBUG_PRINTLN(x)       (Serial1.println(x))
#define SERIAL_DEBUG_PRINT_F(x)       (Serial1.print(F(x)))
#define SERIAL_DEBUG_PRINTLN_F(x)     (Serial1.println(F(x)))
#define SERIAL_DEBUG_PRINT2(x,y)      (Serial1.print(x,y))
#define SERIAL_DEBUG_PRINTLN2(x,y)    (Serial1.println(x,y))
#else
#define SERIAL_DEBUG_PRINT(x)
#define SERIAL_DEBUG_PRINTLN(x)
#define SERIAL_DEBUG_PRINT_F(x)
#define SERIAL_DEBUG_PRINTLN_F(x)
#define SERIAL_DEBUG_PRINT2(x,y)
#define SERIAL_DEBUG_PRINTLN2(x,y)
#endif
#if DEBUG_LEVEL == 0
#define SERIAL_DEBUG_0_PRINT(x)       (Serial1.print(x))
#define SERIAL_DEBUG_0_PRINTLN(x)     (Serial1.println(x))
#define SERIAL_DEBUG_0_PRINT_F(x)     (Serial1.print(F(x)))
#define SERIAL_DEBUG_0_PRINTLN_F(x)   (Serial1.println(F(x)))
#define SERIAL_DEBUG_0_PRINT2(x,y)    (Serial1.print(x,y))
#define SERIAL_DEBUG_0_PRINTLN2(x,y)  (Serial1.println(x,y))
#else
#define SERIAL_DEBUG_0_PRINT(x)   
#define SERIAL_DEBUG_0_PRINTLN(x) 
#define SERIAL_DEBUG_0_PRINT_F(x)   
#define SERIAL_DEBUG_0_PRINTLN_F(x)     
#define SERIAL_DEBUG_0_PRINT2(x,y)      
#define SERIAL_DEBUG_0_PRINTLN2(x,y)
#endif
#endif

#ifndef SERIAL_DEBUG
#define SERIAL_DEBUG_PRINT(x)
#define SERIAL_DEBUG_PRINTLN(x)
#define SERIAL_DEBUG_PRINT_F(x)
#define SERIAL_DEBUG_PRINTLN_F(x)
#define SERIAL_DEBUG_PRINT2(x,y)
#define SERIAL_DEBUG_PRINTLN2(x,y)

#define SERIAL_DEBUG_0_PRINT(x)   
#define SERIAL_DEBUG_0_PRINTLN(x) 
#define SERIAL_DEBUG_0_PRINT_F(x)   
#define SERIAL_DEBUG_0_PRINTLN_F(x)     
#define SERIAL_DEBUG_0_PRINT2(x,y)      
#define SERIAL_DEBUG_0_PRINTLN2(x,y)    
#endif

//********************************************************************

#define ANTPLUS_BAUD_RATE (9600) //!< The moduloe I am using is hardcoded to this baud rate.


//The ANT+ network keys are not allowed to be published so they are stripped from here.
//They are available in the ANT+ docs at thisisant.com
#define ANT_SENSOR_NETWORK_KEY {0xB9, 0xA5, 0x21, 0xFB, 0xBD, 0x72, 0xC3, 0x45}
#define ANT_GPS_NETWORK_KEY    {0xE8, 0xE4, 0x21, 0x3B, 0x55, 0x7A, 0x67, 0xC1}

#if !defined( ANT_SENSOR_NETWORK_KEY ) || !defined(ANT_GPS_NETWORK_KEY)
#error "The Network Keys are missing. Better go find them by signing up at thisisant.com"
#endif

// ****************************************************************************
// ******************************  Defines for Sending Power  *****************
// ****************************************************************************
#define PAGE_SEND_DELAY_MS 250

// ****************************************************************************
// ******************************  GLOBALS  ***********************************
// ****************************************************************************

//Arduino Pro Mini pins to the nrf24AP2 modules pinouts
static const int RTS_PIN = 0; //!< RTS on the nRF24AP2 module
                 //static const int RTS_PIN_INT  = 0; //!< The interrupt equivalent of the RTS_PIN


#if !defined(ANTPLUS_ON_HW_UART)
static const int TX_PIN = 13; //Using software serial for the UART
static const int RX_PIN = 15; //Ditto
static SoftwareSerial ant_serial(TX_PIN, RX_PIN, false, 256); // RXArd, TXArd -- Arduino is opposite to nRF24AP2 module
#else
                 //Using Hardware Serial (0,1) instead
#endif

static ANTPlus        antplus = ANTPlus(RTS_PIN, 14/*SUSPEND*/, 16/*SLEEP*/, 12/*RESET*/);

static ANT_Channel fitness_channel =
{
  0, //Channel Number
  MASTER_DEVICE, //Channel_Type
  0, //Network Number
  DEVCE_TIMEOUT,
  DEVCE_TYPE_FITNESS_EQUIPMENT,
  DEVCE_SENSOR_FREQ,
  DEVCE_FITNESS_LOWEST_RATE,
  0x03, //device number MSB
  0x00, //device number LSB
  ANT_SENSOR_NETWORK_KEY,
  ANT_CHANNEL_ESTABLISH_PROGRESSING,
  FALSE,

  0, //state_counter
};

volatile int rts_ant_received = 0; //!< ANT RTS interrupt flag see isr_rts_ant()

                   //Globals for Power measurement 
Bike_Trainer_with_Power Trainer_Data;
int testpower;
int message_step;

//Timers
unsigned long current_time_ms;
unsigned long last_time_ms;
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

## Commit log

2016-12-13 First Commit
    Arduino Code, working but needs cleanup
2017-02-26 Added PCB Design
    [CycleOpsPro300toANTPlus_V1.0.brd, CycleOpsPro300toANTPlus_V1.0.sch]
2017-02-26 Support for OLED Display
    Major changes to code to output power, torue and cadence to OLCD
    display. Much code cleanup
2017-03-05 Updated PCB design and placed order for PCBs
    [CycleOpsPro300toANTPlus_V1.0.brd, CycleOpsPro300toANTPlus_V1.0.sch, CycleOpsPro300toANTPlus_V1.0_Parts_List.xlsx]
2017-04-09 Added CAD Model and Partslist
    [Battery 14500.SLDPRT, Case XDP04-17 Bottom.SLDDRW, Case XDP04-17 Bottom.SLDPRT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]
2017-04-09 Updated Parts List
    [CycleOpsPro300toANTPlus_V1.0_Parts_List.xlsx]
2017-04-16 Update to Parts List
    [CycleOpsPro300toANTPlus_V1.0_Parts_List.xlsx]
2018-01-20 Updated CAD Model. Minor corrections to schematic. Updated BOM Parts List.
    [Case XDP04-17 Bottom.SLDDRW, Case XDP04-17 Bottom.SLDPRT, Case XDP04-17 Top.SLDPRT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]
2018-04-30 Folder restructure, getting ready for V2 design
    [Battery 14500.SLDPRT, Case XDP04-17 Bottom 8x11.SLDDRW, Case XDP04-17 Bottom.SLDDRW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]
2018-04-30 Fixed a file name
    [Read_CycleOps_V3_Power_V1.ino]
2018-12-24 Switched to low memeory usage OLED library
2018-12-24 Cleaned up the display and fixed a flashing during update
    [Read_CycleOps_V3_Power_V1.ino]
2018-12-24 Bug found in the start data bit code, cleaned up ugly comparison method with the memcmp function. Still getting some current spikes. Going to do some more work looking at clock signal.
    [Read_CycleOps_V3_Power_V1.ino]
2018-12-24 Update Read_CycleOps_V3_Power_V1.ino
    Some minor code cleanup and added a check for torque jumps. This is to stop toque spikes that look to be electrical noise from the hub itself.
    [Read_CycleOps_V3_Power_V1.ino]
2019-01-02 Added volatile qualifier for interrupts
    Added volatile qualifier for interrupts
2019-01-05 Added real error bit detection
    Added feature to look for short pulses during the reading of data bits.
    [Read_CycleOps_V3_Power_V1.ino]
2021-12-05 Corrected Wheel Circumference
    Corrected the wheel circumference such that the real bike wheel rotational velocity matches the virtual wheel such that speed and power are calculated correctly.
    [Read_CycleOps_V3_Power_V1.ino]

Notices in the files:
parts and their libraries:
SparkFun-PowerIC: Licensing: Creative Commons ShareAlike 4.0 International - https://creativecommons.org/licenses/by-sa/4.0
